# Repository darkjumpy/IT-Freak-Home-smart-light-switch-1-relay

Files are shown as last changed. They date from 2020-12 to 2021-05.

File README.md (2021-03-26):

# IT Freak Home smart light switch (1 relay)
DIY, smart and relatively cheap light switch.

## -What IT Freak Home exactly is?
It was a private project of DIY smart home devices which I decide to publish as an open-source project.<br/>
I would like to make an IT Freak Home easy to build, relatively chip alternative for smart home products.
IT Freak Home works based on MQTT communication. I recommend using [Home Assistant](https://www.home-assistant.io/) for this project but if you would like to use something else go free.<br/>This project supports Arduino IDE OTA and has a web interface for a better user experience.

In my free time, I'm working on more smart devices for IT Freak Home so if you are interested you can check my GitHub:octocat: from time to time for more devices.

## -What do you need for a smart light switch?
You will need:
1. ESP8266 (ESP-12E)
1. AMS1117 3.3V
1. Capacitor 470uF 10V (6.3mm x 11mm)
1. Varistor (JVR14N391K)
1. Thermal fuse (TZ-P115/2)
1. 5V SSR relay (Omron G3MB-202P)
1. HI-LINK 5V power supply
1. Screw terminal with 3 pins
1. Custom PCB (You can download gerber files from this repository)
1. 3D printed casing (You can download STL files from this repository)

## -How to build it?
Put all of your parts on the PCB like on the picture:<br/>
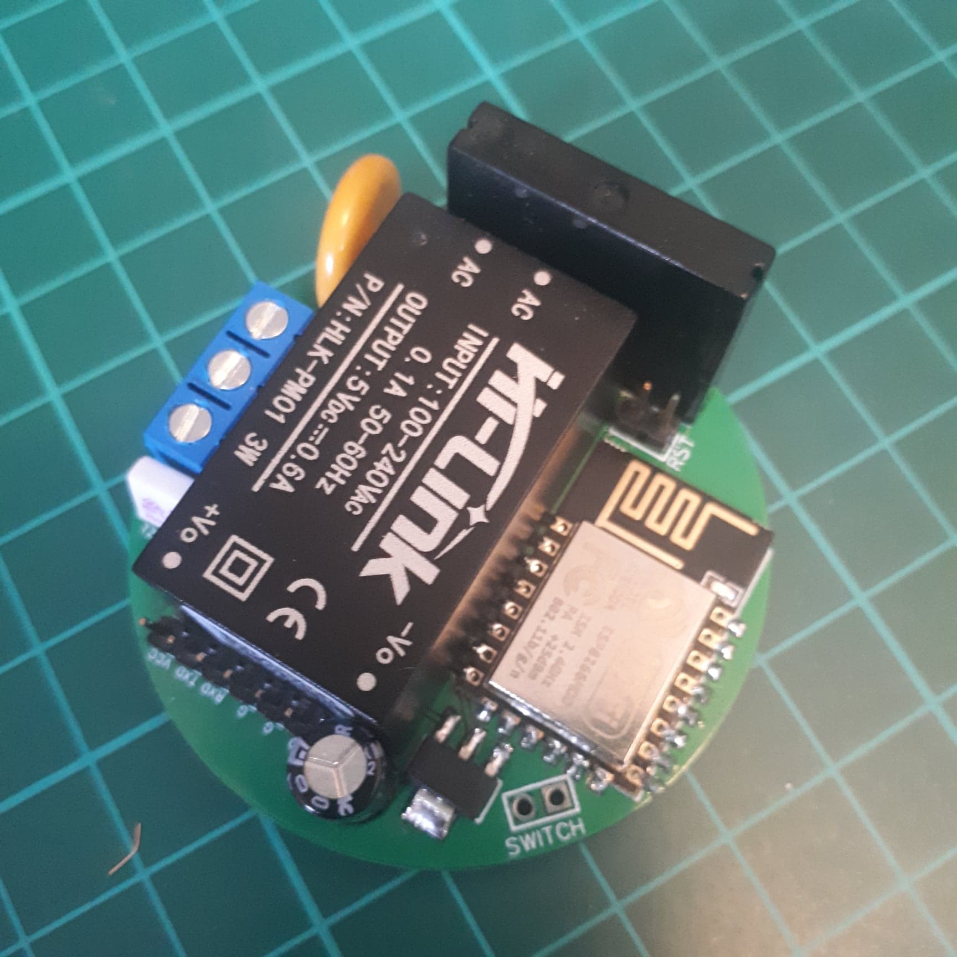
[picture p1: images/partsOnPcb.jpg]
<br/>
On the bottom side of the PCB, you have named where witch cable should go.
**(N-Neutral wire, LI-Live wire, LO-Light out)**<br/>

Attach the bottom part of the casing to the PCB. The plastic thing on the middle should go into a crack in PCB.<br/>
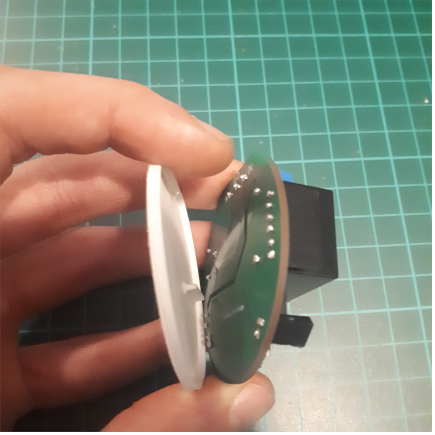
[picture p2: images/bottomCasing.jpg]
<br/>

Now attach the top part of the casing. It should be attached to the power supply casing.<br/>
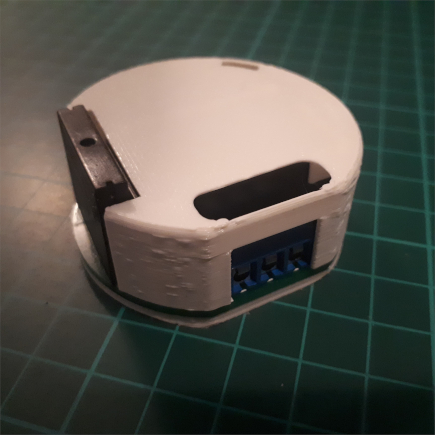
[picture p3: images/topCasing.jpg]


## -How to program it?
You can simply upload the binary file or compile it on your own.<br/><br/>

If you would like to compile it:<br/>

Libraries you will need:
1. StreamString.h
1. modified-WiFiManager.h (You can download this library from this repository)
1. MQTT.h
1. ArduinoJson.h
1. ArduinoOTA.h
1. FS.h  

Download "light-switch.ino", "IT_Freak_home_essentials.h" and modified WiFiManager library. Connect D0 to GND, programming pins to USB-UART converter and USB-UART converter to the PC. Now you can upload this program on your ESP-12E.<br/>
(If you don't have ESP8266 boards installed in your Arduino IDE check this https://github.com/esp8266/Arduino)

## -How to put it behind normal light switch?
(I recommend first configure your smart switch and see if it works)
* **Turn off the power in your home**
* Disassemble your normal light switch
* If you don't have a neutral wire in your electrical box ask the electrician about adding one
* Connect electric wires to screw terminal (On bottom of the PCB you can see where which wire should go)
* Put the smart switch to the electrical box and connect the normal light switch to the smart switch (To the "SWITCH" pins on PCB)
* Assemble your normal light switch to the wall 

## -How to configure it with [Home Assistant](https://www.home-assistant.io/)?
If you have already configured home assistant you should install and configure mosquitto MQTT broker.<br/>
[Here you have how to do it](https://www.home-assistant.io/docs/mqtt/broker#public-broker)<br/><br/>

After this connect to the WiFi access point of your smart switch (password: admin123) and in web browser write 192.168.4.1<br/>
Your browser should show you a configuration page. Go to the setup and complete the form.<br/>
Next, go to the configure WiFi and put here the credentials of your WiFi. (After connecting to WiFi you can find this page under device's IP)<br/>
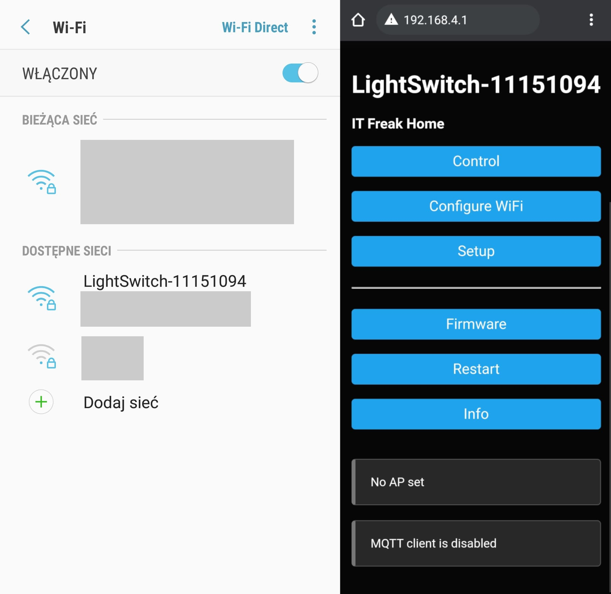
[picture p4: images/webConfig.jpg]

<br/><br/>
If you have enabled MQTT auto discovery your device will show up in [Home Assistant](https://www.home-assistant.io/) under mosquitto broker integration.
<br/>
**Now your device is ready to use!!!** :tada:<br/>

## -If you would like you can buy me a coffee :D
<a href="https://www.buymeacoffee.com/itfreakjake" target="_blank">Buy Me A Coffee</a>

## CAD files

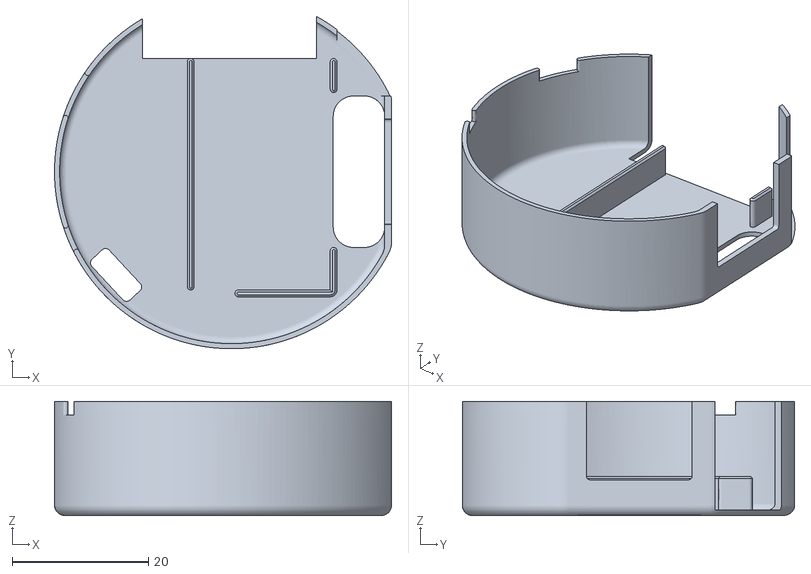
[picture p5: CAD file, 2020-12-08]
3D-models/caseing-top.stl
49.5 x 48.8 x 16.8

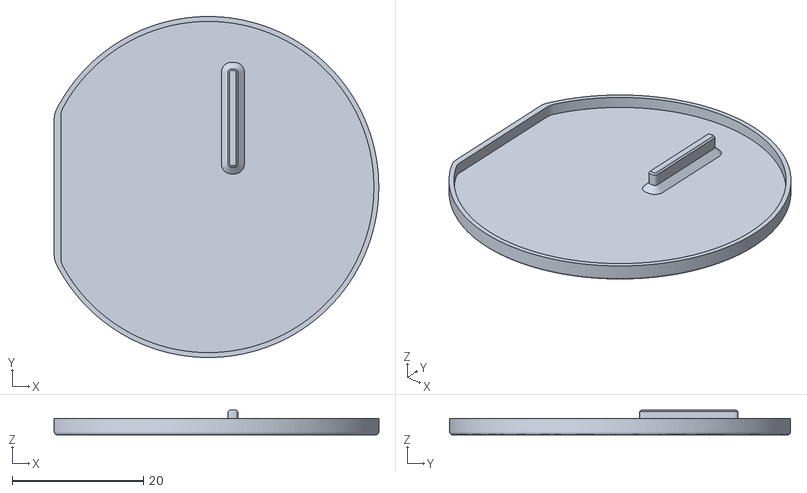
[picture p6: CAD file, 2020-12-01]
3D-models/caseing-bottom.stl
49.5 x 52.0 x 3.80

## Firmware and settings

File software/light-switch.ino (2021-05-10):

//I know the code is a little mess but it's waiting for cleanup ;)
#include <modified-WiFiManager.h>

#define software_version "0.2.7"
#define compatible_hardware "ESP-12E"
#define compatible_device "Single light switch"
#define github_project_link "https://github.com/IT-freak-Jake/IT-Freak-Home-smart-light-switch-1-relay"
#define confSize 700
#define mqttBufferSize 1024

String host_name="LightSwitch-"+String(ESP.getChipId());

#define light_on_state "ON"
#define light_off_state "OFF"

#define light_on_command "ON"
#define light_off_command "OFF"

#define RELAY 14
#define SWITCH 13

String command_topic, state_topic, attributes_topic, config_topic, icon;
boolean isLightOn=false, prevSwitchState;

boolean isDynamicIconsEnabled=false;
char icon_off[32]="mdi:lightbulb";
char icon_on[32]="mdi:lightbulb-on";

WiFiManagerParameter custom_enable_dynamic_icons("enable_dynamic_icons", "Enable dynamic icons", "f", 2, "type=\"checkbox\" style=\"width: 20px\" onchange=\"changeDynamicIcons()\"", WFM_LABEL_AFTER);
WiFiManagerParameter custom_icon_off("icon_off", "Icon", icon_off, 31, "placeholder=\"mdi:lightbulb\"");
WiFiManagerParameter custom_icon_on("icon_on", "Icon on ON", icon_on, 31, "placeholder=\"mdi:lightbulb-on\"");
WiFiManagerParameter custom_icon_div("<div id=\"icon\" style=\"padding: 0px\">");
WiFiManagerParameter custom_additional_js(R"(<script>
document.getElementById("enable_dynamic_icons").checked = document.getElementById("enable_dynamic_icons").value=="t";
var labels = document.getElementsByTagName('LABEL');
for (var i = 0; i < labels.length; i++) {
  if (labels[i].htmlFor != '') {
     var elem = document.getElementById(labels[i].htmlFor);
     if (elem)
        elem.label = labels[i];         
  }
}
changeDynamicIcons();
function changeDynamicIcons()
{
  const isChecked=document.getElementById("enable_dynamic_icons").checked;
  if(isChecked)
  {
    document.getElementById("icon_off").label.innerHTML = "Icon on OFF";
    document.getElementById("icon").style.display = "initial";
  }
  else
  {
    document.getElementById("icon_off").label.innerHTML = "Icon";
    document.getElementById("icon").style.display = "none";
  }
}
</script>)");

#include "IT_Freak_Home_essentials.h"

void WiFiManager::handleControl() {
  DEBUG_WM(DEBUG_VERBOSE,F("<- HTTP Control"));
  if (captivePortal()) return;
  handleRequest();

  if (server->hasArg("action"))
  {
    String action = server->arg("action");
    if (action=="on")
    {
      isLightOn=true;
      if(mqttClient.connected())
      {
        msg = light_on_state;
        mqttClient.publish(state_topic, msg);
        if(isDynamicIconsEnabled && isDiscoveryOn)resendConfig();
      }
      digitalWrite(RELAY, HIGH);
    }
    else if (action=="off")
    {
      isLightOn=false;
      if(mqttClient.connected())
      {
        msg = light_off_state;
        mqttClient.publish(state_topic, msg);
        if(isDynamicIconsEnabled && isDiscoveryOn)resendConfig();
      }
      digitalWrite(RELAY, LOW);
    }
  }
  
  String page = getHTTPHead("Control");
  page += "<h1>";
  page += (device_user_name[0]!='\0'?device_user_name:host_name.c_str());
  page += "</h1>";
  page += "Switch is ";
  page += (isLightOn?"ON":"OFF");
  page += "<br/><br/>";
  page += "<button ";
  page += isLightOn?"style=\"height: 70px;line-height: 1rem;\" class=\"D\" onclick=\"location.href='?action=off';\"":"style=\"background-color: #44bb44;height: 70px;line-height: 1rem;\" onclick=\"location.href='?action=on';\"";
  page += "><h3>Turn ";
  page += (isLightOn?"OFF":"ON");
  page += "</h3></button><br/><br/>";
  page += "<hr><br/>";
  page += "<button style=\"width:47%;\" onclick=\"location.href='/';\" >Back</button>";
  page += "<button style=\"width:47%; margin-left: 6%\" onclick=\"location.href='?';\" >Refresh</button>";
  reportStatus(page);
  reportMqttStatus(page);
  page += FPSTR(HTTP_END);

  server->sendHeader(FPSTR(HTTP_HEAD_CL), String(page.length()));
  server->send(200, FPSTR(HTTP_HEAD_CT), page);
  if(_preloadwifiscan) WiFi_scanNetworks(_scancachetime,true); 
}

void addAdditionalParameters()
{
  wm.addParameter(&custom_br);
  wm.addParameter(&custom_enable_dynamic_icons);
  wm.addParameter(&custom_br);
  wm.addParameter(&custom_br);
  wm.addParameter(&custom_icon_off);
  wm.addParameter(&custom_icon_div);
  wm.addParameter(&custom_icon_on);
  wm.addParameter(&custom_end_div);
  wm.addParameter(&custom_additional_js);
  wm.addParameter(&custom_hr);
}

void setAdditionalParameters()
{
  custom_enable_dynamic_icons.setValue(isDynamicIconsEnabled?"t":"f",2);
  custom_icon_off.setValue(icon_off, 32);
  custom_icon_on.setValue(icon_on, 32);
  String stringBuffer;
  if(icon_off[0]=='\0'){
    stringBuffer="mdi:lightbulb";
    stringBuffer.toCharArray(icon_off, 32);
  }
  if(icon_on[0]=='\0'){
    stringBuffer="mdi:lightbulb-on";
    stringBuffer.toCharArray(icon_on, 32);
  }
  icon=icon_off;
}

void reloadAdditionalParameters()
{
  String stringBuffer;
  if(conf.containsKey("isDynamicIconsEnabled"))isDynamicIconsEnabled = conf["isDynamicIconsEnabled"];
  if(conf.containsKey("icon_off"))
  {
    stringBuffer = conf["icon_off"].as<String>();
    stringBuffer.toCharArray(icon_off, 32);
  }
  if(conf.containsKey("icon_on"))
  {
    stringBuffer = conf["icon_on"].as<String>();
    stringBuffer.toCharArray(icon_on, 32);
  }
}

void saveAdditionalParameters()
{
  if((strncmp(custom_enable_dynamic_icons.getValue(), "f", 1) == 0)==true || (strncmp(custom_enable_dynamic_icons.getValue(), "t", 1) == 0)==true){
    conf["isDynamicIconsEnabled"]=true;}
  else{
    conf["isDynamicIconsEnabled"]=false;}
  conf["icon_off"] = custom_icon_off.getValue();
  Serial.println(conf["icon_off"].as<String>());
  conf["icon_on"] = custom_icon_on.getValue();
  Serial.println(conf["icon_on"].as<String>());
}

void pinsSetup()
{
  Serial.println("Setting up pins");
  pinMode(RELAY, OUTPUT); 
  pinMode(SWITCH, INPUT_PULLUP);
  digitalWrite(RELAY, LOW);
  prevSwitchState=digitalRead(SWITCH);
  Serial.println("Done!");
}

void mqttTopicsSetup()
{
  Serial.println("Setting up MQTT topics");
  command_topic=String(mqtt_prefix)+"/"+nodeID;
  state_topic=String(mqtt_prefix)+"/"+nodeID+"/state";
  attributes_topic=String(mqtt_prefix)+"/"+nodeID+"/attributes";
  config_topic=String(discoveryPrefix)+"/switch/"+host_name+"/switch1/config";
  Serial.println("Done!");
}

void mqttStatusResend()
{
  Serial.println("Resending all MQTT messages");
  if(isDiscoveryOn)
  {
    resendConfig();
    delay(20);
  }
  else
  {
    Serial.println("Auto discovery disabled");
  }
  msg = isLightOn ? light_on_state:light_off_state;
  mqttClient.publish(state_topic, msg);
  resendAttributes();
}

void switch_handle()
{
  if(digitalRead(SWITCH) != prevSwitchState)
  {
    isLightOn = !isLightOn;
    digitalWrite(RELAY, isLightOn);
    msg = isLightOn ? light_on_state:light_off_state;
    Serial.print("Light is ");  
    Serial.println(msg);  
    if(mqttClient.connected())mqttClient.publish(state_topic, msg);
    if(isDynamicIconsEnabled && isDiscoveryOn && mqttClient.connected())resendConfig();
    delay(20);
    prevSwitchState=digitalRead(SWITCH);
  }  
}

void resendConfig()
{
  Serial.println("Sending auto discovery config");
  if(isDynamicIconsEnabled)icon=isLightOn?icon_on:icon_off;
  StaticJsonDocument<570> doc;
  StaticJsonDocument<128> doc2;
  String obj;
  obj="";
  doc2["identifiers"] = host_name;
  doc2["name"] = (device_user_name[0]!='\0'?device_user_name:host_name.c_str());
  doc2["manufacturer"] = mark;
  doc2["model"] = compatible_device;
  doc2["sw_version"] = software_version;

  doc["device"] = doc2;
  doc["name"] = (device_user_name[0]!='\0'?device_user_name:host_name.c_str());
  doc["unique_id"] = host_name;
  doc["command_topic"] = command_topic;
  doc["state_topic"] = state_topic;
  doc["json_attributes_topic"] = attributes_topic;
  doc["retain"] = false;
  doc["payload_on"] = light_on_command;
  doc["payload_off"] = light_off_command;
  doc["state_on"] = light_on_state;
  doc["state_off"] = light_off_state;
  doc["icon"] = icon;
  serializeJson(doc, obj);
  Serial.println(config_topic);
  Serial.print("Sending auto discovery conf: "); Serial.println(obj);
  mqttClient.publish(config_topic, obj);
}

void setup() 
{
  setupProcess();
}

void loop() 
{
    wifi_handle();
    mqtt_handle();
    ota_handle();
    switch_handle();
}

void mqtt_message_handle(String topic, String payload)
{
  if(payload==light_on_command)
  {
    isLightOn=true;
    msg = light_on_state;
    mqttClient.publish(state_topic, msg);
    digitalWrite(RELAY, HIGH);
    if(isDynamicIconsEnabled && isDiscoveryOn)resendConfig();
  }
  else if(payload==light_off_command)
  {
    isLightOn=false;
    msg = light_off_state;
    mqttClient.publish(state_topic, msg);
    digitalWrite(RELAY, LOW);
    if(isDynamicIconsEnabled && isDiscoveryOn)resendConfig();
  }
}

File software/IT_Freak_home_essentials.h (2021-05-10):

//I know the code is a little mess but it's waiting for cleanup ;)
#include "StreamString.h" 
#include <MQTT.h>   
#include <ArduinoJson.h>  
#include <ArduinoOTA.h> 
#include <FS.h> 

#define mark "IT Freak Home"

void addAdditionalParameters();
void setAdditionalParameters();
void reloadAdditionalParameters();
void saveAdditionalParameters();
void resendAttributes();
void resendConfig();
void pinsSetup();
void mqttTopicsSetup();
void mqttStatusResend();
void reloadConfigSettings();
void saveParamsCallback();
void saveConfigCallback();
void apStarted(WiFiManager *myWiFiManager);
bool connectMqtt();
bool connectMqttOptions();
void mqtt_message_handle(String topic, String payload);
void mqttMessageReceived(String &topic, String &payload);

static const char HTTP_FIRMWARE[] PROGMEM =
  R"(<!DOCTYPE html>
     <html lang='en'>
     <head>
         <meta charset='utf-8'>
         <meta name='viewport' content='width=device-width,initial-scale=1'/>
     </head>
     <body>
     <h3>Firmware info</h3>
     <hr/>
     <dt><strong>Manufacturer:</strong></dt>
     <dd>{c}</dd>
     <dt><strong>Device:</strong></dt> 
     <dd>{r}</dd>
     <dt><strong>Firmware verison:</strong></dt> 
     <dd>{v}</dd>
     <dt><strong>GitHub project:</strong></dt> 
     <dd><em><a href="{h}" target="_blank">GitHub link</a></em></dd>
     <br/>
     <h3>Upload firmware</h3>
     <hr/>
     <form method='POST' action='' enctype='multipart/form-data'>
         Firmware:<br>
         <input type='file' accept='.bin,.bin.gz' name='firmware'>
         <input type='submit' value='Update firmware'>
     </form>
     </body>
     </html>)";
static const char successResponse[] PROGMEM = 
  "<META http-equiv=\"refresh\" content=\"15;URL=/\">Update Success! Rebooting...";

StaticJsonDocument<confSize> conf;
String serializedConf;

File confFile;
bool isOtaUploading=false, isOtaStarted=false, isDisconnected=true, needMqttConnect=false, isServerOnline=true, needRestart=false, isApStarted=false, disableMqtt=false;
String nodeID, msg, topic, apName;
unsigned long prevMillisTimeToReset=0, intervalTimeToReset=10000, prevMillisReconnect=0, intervalReconnect=240000, 
lastMqttConnectionAttempt=0, intervalMqttReconnect=15000, prevSetMqttProps=0, intervalSetMqttProps=20000;

WiFiClient net;
MQTTClient mqttClient(mqttBufferSize);

char device_user_name[64];
char mqtt_server[48];
char mqtt_user[64];
char mqtt_password[64];
char mqtt_client_name[16];
char mqtt_port[5]="1883";
char mqtt_prefix[16]="Home";
char serverStatusTopic[64]="homeassistant/status";
char serverOnlineStatusPayload[64]="online";
char serverOfflineStatusPayload[64]="offline";
boolean isDiscoveryOn=true;
boolean isMqttEnabled=true;
char discoveryPrefix[64]="homeassistant";
boolean isArduinoOtaEnabled=false;

WiFiManager wm;

String device_name_placeholder="placeholder=\""+host_name+"\"",
mqtt_client_name_placeholder="placeholder=\"Default: IFH-"+String(ESP.getChipId())+"\"";
WiFiManagerParameter custom_device_user_name("device_user_name", "Device name", device_user_name, 63, device_name_placeholder.c_str());
WiFiManagerParameter custom_enable_mqtt("enable_mqtt", "Enable MQTT client", "t", 2, "type=\"checkbox\" checked style=\"width: 20px\" onchange=\"changeMqtt()\"", WFM_LABEL_AFTER);
WiFiManagerParameter custom_mqtt_server("mqtt_server", "MQTT server", mqtt_server, 47, "placeholder=\"IP address or domain\"");
WiFiManagerParameter custom_mqtt_user("mqtt_user", "MQTT user", mqtt_user, 63, "placeholder=\"Login\"");
WiFiManagerParameter custom_mqtt_password("mqtt_password", "MQTT password", mqtt_password, 63, "type=password placeholder=\"Password\"");
WiFiManagerParameter custom_mqtt_client_name("mqtt_client_name", "MQTT client name", mqtt_client_name, 15, mqtt_client_name_placeholder.c_str());
WiFiManagerParameter custom_mqtt_port("mqtt_port", "MQTT port", mqtt_port, 4, "placeholder=\"Default: 1883\"");
WiFiManagerParameter custom_mqtt_prefix("mqtt_prefix", "MQTT device prefix", mqtt_prefix, 15, "placeholder=\"Default: Home\"");
WiFiManagerParameter custom_server_status_topic("server_status_topic", "Server status topic", serverStatusTopic, 63, "placeholder=\"Default: homeassistant/status\"");
WiFiManagerParameter custom_server_online_payload("server_online_status_payload", "Server online payload", serverOnlineStatusPayload, 63, "placeholder=\"Default: online\"");
WiFiManagerParameter custom_server_offline_payload("server_offline_status_payload", "Server offline payload", serverOfflineStatusPayload, 63, "placeholder=\"Default: offline\"");
WiFiManagerParameter custom_enable_auto_discovery("enable_auto_discovery", "Enable MQTT auto discovery", "t", 2, "type=\"checkbox\" checked style=\"width: 20px\" onchange=\"changeDiscovery()\"", WFM_LABEL_AFTER);
WiFiManagerParameter custom_br("<br/>");
WiFiManagerParameter custom_hr("<hr/>");
WiFiManagerParameter custom_mqtt_div("<div id=\"mqttSetup\" style=\"padding: 0px\">");
WiFiManagerParameter custom_auto_discovery_div("<div id=\"autoDiscoverySetup\" style=\"padding: 0px\">");
WiFiManagerParameter custom_end_div("</div>");
WiFiManagerParameter custom_discovery_prefix("discovery_prefix", "MQTT auto discovery prefix", discoveryPrefix, 63, "placeholder=\"Default: homeassistant\"");
WiFiManagerParameter custom_enable_arduino_ota("enable_arduino_ota", "Enable Arduino IDE OTA", "f", 2, "type=\"checkbox\" style=\"width: 20px\"", WFM_LABEL_AFTER);
WiFiManagerParameter custom_js(R"(<script>
document.getElementById("enable_mqtt").checked = document.getElementById("enable_mqtt").value=="t";
document.getElementById("enable_auto_discovery").checked = document.getElementById("enable_auto_discovery").value=="t";
document.getElementById("enable_arduino_ota").checked = document.getElementById("enable_arduino_ota").value=="t";

changeDiscovery();
changeMqtt();

function changeDiscovery()
{
  const isEnableAutoDiscoveryChecked=document.getElementById("enable_auto_discovery").checked;
  if(isEnableAutoDiscoveryChecked)
  {
    document.getElementById("autoDiscoverySetup").style.display = "initial";
  }
  else
  {
    document.getElementById("autoDiscoverySetup").style.display = "none";
  }
}

function changeMqtt()
{
  const isEnableMqttChecked=document.getElementById("enable_mqtt").checked;
  const isEnableAutoDiscoveryChecked=document.getElementById("enable_auto_discovery").checked;
  if(isEnableMqttChecked)
  {
    document.getElementById("mqttSetup").style.display = "initial";
    if(isEnableAutoDiscoveryChecked){
      document.getElementById("autoDiscoverySetup").style.display = "initial";
    }
  }
  else
  {
    document.getElementById("mqttSetup").style.display = "none";
  }
}
</script>)");

bool isCharArrayDigit(char *charArray)
{
  bool isCharArrayDigit=true;
  for(int i=0; i<sizeof(charArray) && isCharArrayDigit; i++)
  {
    isCharArrayDigit=isDigit(charArray[i]);
  }
  return isCharArrayDigit;
}
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

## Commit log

2020-10-09 First commit (0.1v)
2020-10-10 Added link to bridge (0.1v)
2020-12-01 Custom PCB added
2020-12-08 Added places for thermal fuse and varistor
2021-03-26 Create de
